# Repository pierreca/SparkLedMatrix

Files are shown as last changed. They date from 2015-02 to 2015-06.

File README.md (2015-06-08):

The end goal of this project is to build a Matrix of 16 8x8 LED Matrices (NFM-12883) driven from a spark core that can be used to display... stuff :grin:

## Current status:
- [x] Code to make text scroll across multiple matrices seems to work with 2 matrices.
- [x] First version of the PCB works fine (silkscreen isn't great though)
- [x] Connect the current prototype to the Spark cloud
- [x] Display messages sent to the device using the Spark cloud API
- [x] Clean PCB silk screen
- [x] Order more PCBs
- [x] Build more Matrices
- [x] Build and order a "motherboard" on which LED matrix modules will be connected.
- [x] Test the "motherboard".
- [x] Cleanup code style.
- [x] Implement "Line" abstraction layer that will allow to update and render both lines independently
- [x] Design case with OpenBeam and laser-cut acrylic
- [x] Build website to simply send messages to the LED Matrix
- [X] Build an API endpoint in the website.
- [ ] Add UI to turn on/off the LED Matrix from the Azure website. (Right the equivalent can be done by sending empty messages)
- [ ] Optimize rendering routine (see below in the "Optimization Opportunity section")

## Hardware
* [NFM-12883AS-11 LED Matrix](https://upverter.com/upn/b3a03be171307eb0/)
* [AS1100PL driver (MAX7219 drop-in replacement)](https://www.modmypi.com/as1100pl-led-driver)
* [Spark Core](http://www.spark.io)
* Custom Backpack PCB [Upverter](https://upverter.com/pierreca/2dc3fadd41948de2/NFM-12883-Backpack/) - [OshPark](https://oshpark.com/shared_projects/Awyc02gR)
* Custom Motherboard PCB [Upverter](https://upverter.com/pierreca/2f7e1367325db8bc/Spark-LED-Matrix-Motherboard-2/) - [Oshpark] (https://oshpark.com/shared_projects/4Sw3dNy7)

## Custom PCB
The backpack is my first PCB built using Upverter and OshPark. It's exactly the size of an NFM-12883 LED Matrix, and has the LED matrix on one side, and the driver and passive components on the other, allowing to line-up horizontally and/or vertically  multiple LED matrices.

The motherboard is my second PCB, also built using Upverter and OshPark. it fits 2 lines of 8 matrices each.

## Code
Currently the code is super basic and just scrolls or displays statically a message received from a Spark Cloud API across LED Matrices hooked up to a spark core. the code is written so that adding more LED Matrices is really easy and amounts to just changing one value.

### Making the message scroll
The LedControl library found on spark.io is a port from the Arduino LedControl library and contains basic functions such as piloting each LED individually, displaying letters using a monospaced font (called cp437) and "tweening" letters meaning scrolling a letter out while the next scrolls in.

Since this was a little too basic to obtain a message scrolling on multiple adjacent LED matrices I wrote additional functions that make text scroll across multiple matrices in 2 different ways: either using the default monospaced font (which will always amount to one letter per matrix) or that trims whitespace to make it more readable and waste less columns. I've also added a method to simply statically display text on multiple matrices (trimming spaces).

### Optimization opportunity
The current rendering routine is column-based, which means we calculate and render columns one by one. this is based of the LedControl library implementation but it's very inefficient since each column takes 8 SPI messages to transfer (one for each LED). Switching to a line-based rendering algorithm would require only one SPI message per line, which means we'd render a full LED matrix in 8 messages instead of 64.

### Case design
I wanted to do something simple with OpenBeam aluminium extrusions, but the form-factor doesn't allow for use of their regular L-brackets. Instead, I'm laser-cutting acrylic plates (black on the sides, dark transparent grey in front). The current version doesn't account for material lost during laser-cutting (meaning the edges are not perfectly aligned, there's a 0.5 millimeters error) and does not include mounting holes on the inside plate and power-supply cable hole at the back (I manually drilled those).

### Website
The SparkLedServer folder contains a super simple node.js/express based app that can be deployed to any cloud infrastructure (mine went on Azure). It will require the Spark access token and device ID in environment variables to function (otherwise you'll get an Authentication error).
Since it's super easy and quick to change these in Azure, I'd rather have the service configured this way than using the Spark/Particle authentication widget since I don't want to have to enter my username/password every time. Even though it means that anyone can access the service and send messages to the device. I'll change that if it becomes a problem. 

### API
The API is extremely simple and also described in index.js. It's just a REST endpoint at the /api path that needs to be sent a POST request with the following parameters:
* line: 0 or 1 for first or second line
* scrollDelay: a postive integer of the delay between each iteration of the scrolling mechanism, in milliseconds. 0 means no scrolling.
* message: the message to be sent, must be less than 63 characters (Particle API limitation).

## Pictures
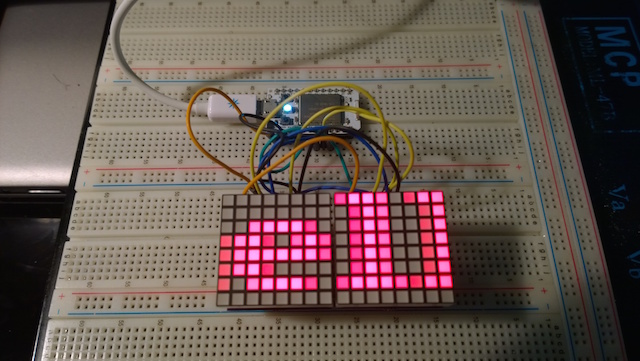
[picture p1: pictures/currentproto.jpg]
Current prototype

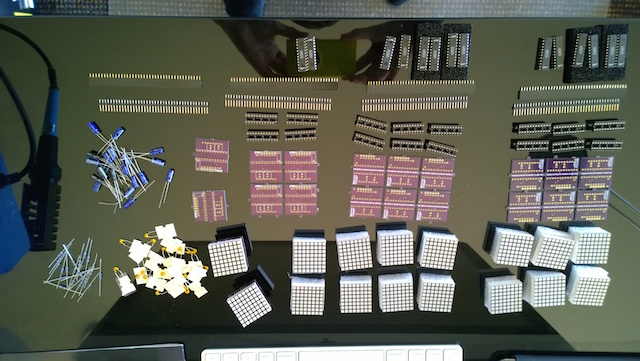
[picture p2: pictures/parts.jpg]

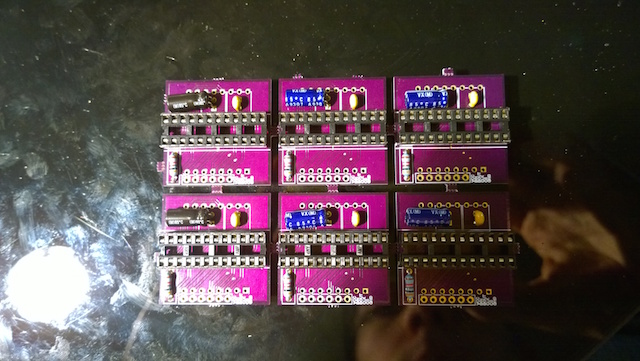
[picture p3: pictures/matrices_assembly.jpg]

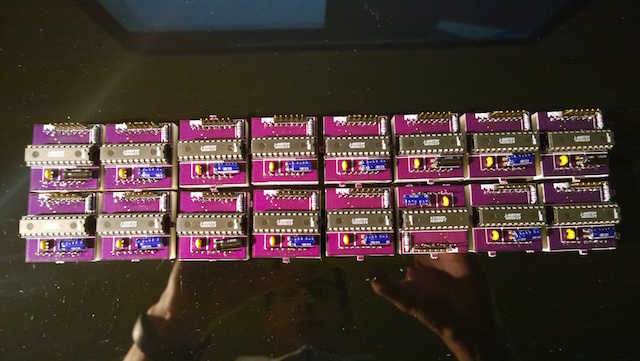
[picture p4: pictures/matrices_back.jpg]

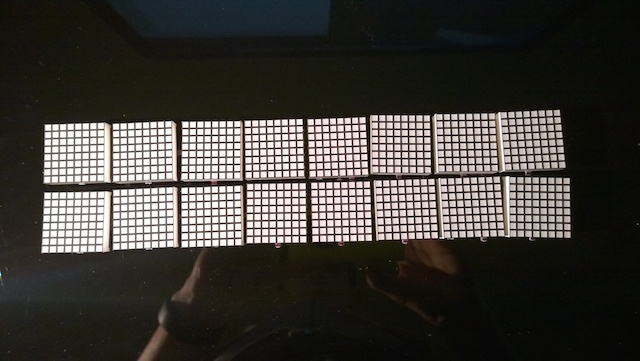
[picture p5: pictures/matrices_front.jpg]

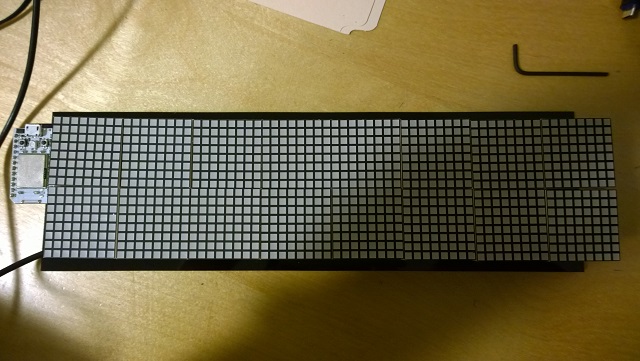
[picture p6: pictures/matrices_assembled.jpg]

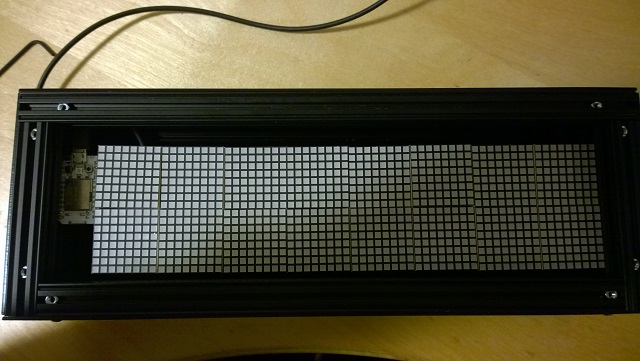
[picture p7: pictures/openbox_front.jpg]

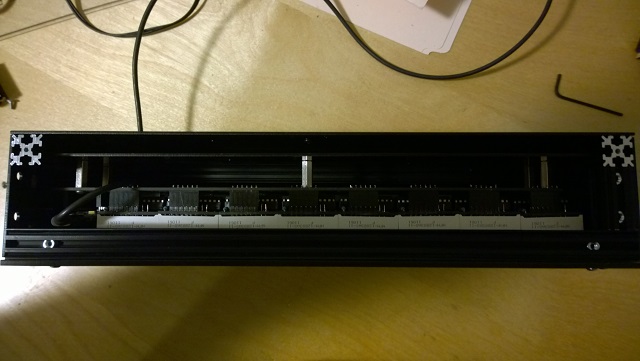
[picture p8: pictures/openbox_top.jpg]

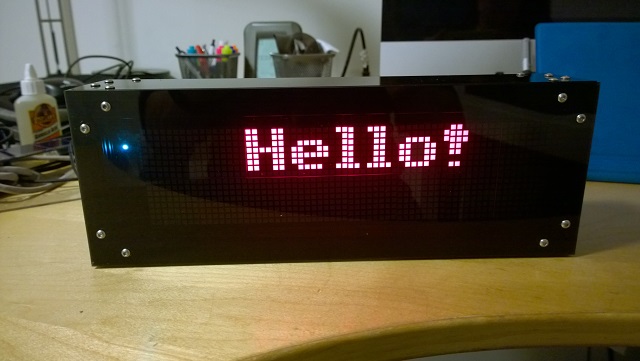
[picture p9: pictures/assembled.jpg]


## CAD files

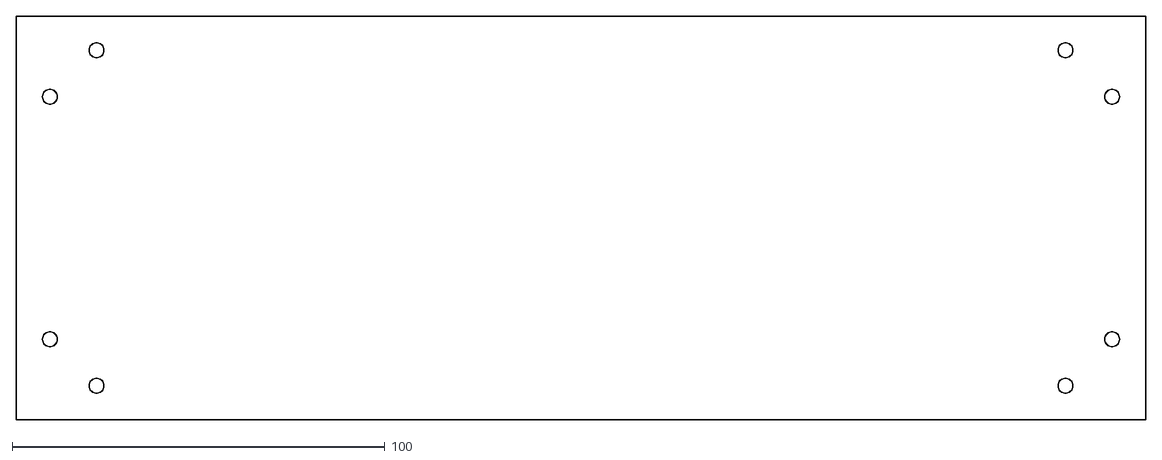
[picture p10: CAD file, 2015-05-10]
case/exports/front_plate.dxf
303.2 x 108.2

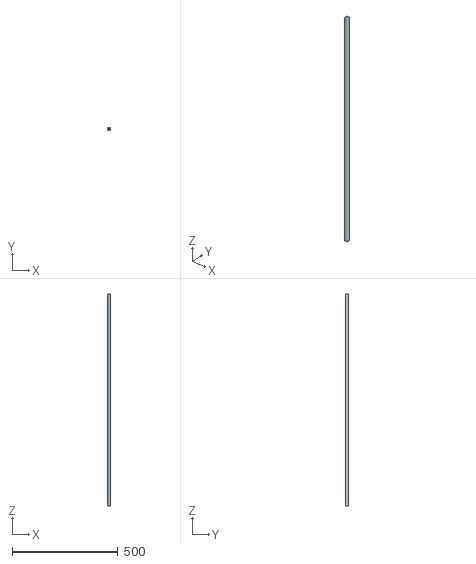
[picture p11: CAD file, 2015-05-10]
case/ob_1515.stl
15.0 x 15.0 x 1000.0

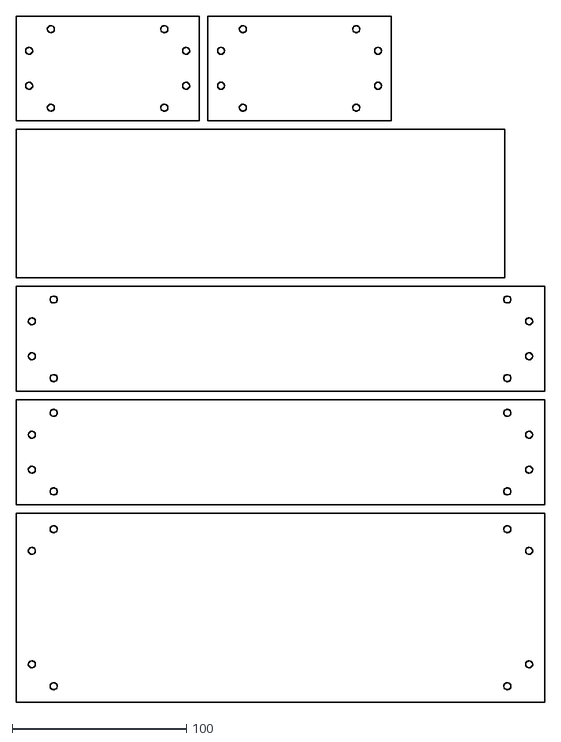
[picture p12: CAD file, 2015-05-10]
case/exports/case_flat.dxf
303.2 x 393.2

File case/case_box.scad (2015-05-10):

use <case_elements.scad>;
include <case_dimensions.scad>;

// file ob_1515.stl was found from:
// http://www.thingiverse.com/thing:30521/#files

module ob_1515(length)
{
    intersection()
    {
        cube([20,20,length]);
        import("ob_1515.stl");
    }
}

module ob_chassis(offset_x, offset_y, offset_z)
{
translate([offset_x, offset_y, offset_z])
{
    // Front, Horizontal
    translate([0,0,ob_width])
        rotate([0, 90, 0])
            ob_1515(300);

    translate([ob_width, 0, 90 + ob_width])
        rotate([0, 90, 0])
            ob_1515(270);

    // Back, Horizontal
    translate([0, lr_height - ob_width, ob_width])
        rotate([0, 90, 0])
            ob_1515(300);

    translate([ob_width, lr_height - ob_width, 90 + ob_width])
        rotate([0, 90, 0])
            ob_1515(270);

    // Left, Vertical
    translate([0,0, ob_width])
        ob_1515(90);
        
    translate([0, 30 + ob_width, ob_width])
        ob_1515(90);

    // Right, Vertical
    translate([300 - ob_width,0, ob_width])
        ob_1515(90);
        
    translate([300 - ob_width, 30 + ob_width, ob_width])
        ob_1515(90);

         
    // Left, Horizontal
    translate([0, ob_width, ob_width])
        rotate([-90, 0, 0])
            ob_1515(30);

           
    translate([0, ob_width, 90 + ob_width])
        rotate([-90, 0, 0])
            ob_1515(30);

    // Right, Horizontal
    translate([300 - ob_width, ob_width, ob_width])
        rotate([-90, 0, 0])
            ob_1515(30);
            
    translate([300 - ob_width, ob_width, 90 + ob_width])
        rotate([-90, 0, 0])
            ob_1515(30);
}
}

module side_plates()
{
    // Back plate
    translate([0, 60 + 2 * black_thickness, 0])
        rotate([90,0,0]) 
            fb_plate(0,0);

    // Front plate
    translate([0, black_thickness, 0])
        rotate([90,0,0]) 
            fb_plate(0,0);

    // Top plate
    translate([0, black_thickness, fb_height - black_thickness])
        tb_plate(0,0);

    // Bottom plate
    translate([0, black_thickness, 0])
        tb_plate(0,0);

    // Left plate
    translate([black_thickness, black_thickness, black_thickness])
        rotate([0, -90, 0])
            lr_plate(0, 0);

    // Right plate
    translate([fb_width, black_thickness, black_thickness])
        rotate([0, -90, 0])
            lr_plate(0, 0);

    // Mounting plate
    translate([10, 60 - 7.5 + black_thickness, 10])
        rotate([90,0,0]) 
            int_plate(0,0);
}

ob_chassis(black_thickness, black_thickness, black_thickness);

side_plates();

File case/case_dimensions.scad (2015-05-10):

black_thickness = 1.5875;
smoke_thickness = 3.175;

ob_width = 15;
slot_depth = 5;

/****** dimensions ******/
// front/back
fb_width = 300 + 2 * black_thickness;
fb_height = 90 + ob_width + 2 * black_thickness;

// left/right
lr_width = 90 + ob_width;
lr_height = 30 + 2 * ob_width;

// top/bottom
tb_width = fb_width;
tb_height = lr_height;

// mounting plate
int_width = 270 + 2 * slot_depth;
int_height = 90 - ob_width + 2 * slot_depth;

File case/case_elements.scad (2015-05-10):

include <case_dimensions.scad>

module black_plate(width, height)
{
    color("black")
        cube([width, height, black_thickness]);   
}

module smoke_plate(width, height)
{
    color("gray")
        cube([width, height, black_thickness]);   
}

module hole(offset_x, offset_y)
{
    translate([offset_x, offset_y, 0])
        cylinder(h=10, r=2, center=true);
}

module fb_plate(offset_x, offset_y) 
{
    a = 20 + black_thickness;
    b = 7.5 + black_thickness;
    
    translate([offset_x, offset_y, 0])
        difference()
        {
            black_plate(fb_width, fb_height);
            hole(a, b);
            hole(b, a);
            hole(b, fb_height - a);
            hole(a, fb_height - b);
            hole(fb_width - a, b);
            hole(fb_width - b, a);
            hole(fb_width - a, fb_height - b);
            hole(fb_width - b, fb_height - a);
        }
}

module lr_plate(offset_x, offset_y) 
{
    a = 20;
    b = 7.5;
    
    translate([offset_x, offset_y, 0])
        difference()
        {
            black_plate(lr_width, lr_height);
            hole(a, b);
            hole(b, a);
            hole(b, lr_height - a);
            hole(a, lr_height - b);
            hole(lr_width - a, b);
            hole(lr_width - b, a);
            hole(lr_width - a, lr_height - b);
            hole(lr_width - b, lr_height - a);
        }
}

module tb_plate(offset_x, offset_y) 
{
    a = 20 + black_thickness;
    b = 7.5 + black_thickness;
    c = 20;
    d = 7.5;
    
    translate([offset_x, offset_y, 0])
        difference()
        {
            black_plate(tb_width, tb_height);
            hole(a, d);
            hole(b, c);
            hole(b, tb_height - c);
            hole(a, tb_height - d);
            hole(tb_width - a, d);
            hole(tb_width - b, c);
            hole(tb_width - a, tb_height - d);
            hole(tb_width - b, tb_height - c);
        }
}

module int_plate(offset_x, offset_y)
{
    translate([offset_x, offset_y, 0])
        black_plate(int_width, int_height);
}

module front_plate()
{
    fb_plate(0,0);
}

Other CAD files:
case/case_flat.scad
case/front_plate.scad

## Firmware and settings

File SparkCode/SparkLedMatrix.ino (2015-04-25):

#include "DisplayLine.h"

#define MATRIX_PER_LINE 8
#define LINE_COUNT 2
#define SPARK_API_MSG_SIZE 63

DisplayLine* lines[LINE_COUNT];

uint8_t cs_0 = A5;
uint8_t clk_0 = A6;
uint8_t din_0 = A7;

uint8_t cs_1 = D0;
uint8_t clk_1 = D1;
uint8_t din_1 = D2;

char recvBuffer[SPARK_API_MSG_SIZE];
int recvBufferLength = 0;

bool newMessage = false;
int activeLine = 0;

void setup() {
    lines[0] = new DisplayLine(din_0, clk_0, cs_0, MATRIX_PER_LINE); // DIN, CLK, CS, HowManyDisplays
    lines[1] = new DisplayLine(din_1, clk_1, cs_1, MATRIX_PER_LINE); // DIN, CLK, CS, HowManyDisplays

    lines[0]->activate(8);
    lines[0]->setScrollDelay(50);
    lines[0]->setText("Hello!", 7);

    lines[1]->activate(8);

    Spark.variable("recvBuffer", recvBuffer, STRING);
    Spark.variable("activeLine", &activeLine, INT);
    Spark.variable("recvBufferLength", &recvBufferLength, INT);
    Spark.function("setMessage", setMessage);
    Spark.function("setActiveLine", setActiveLine);
    Spark.function("setScrollDelay", setScrollDelay);
}

void loop() {
    if (newMessage) {
        lines[activeLine]->setText(recvBuffer, recvBufferLength);
        newMessage = false;
    }

    for (int i = 0; i < LINE_COUNT; i++) {
        lines[i]->refreshDisplay();
    }
}

int setMessage(String msg) {
    recvBufferLength = msg.length() + 1;
    msg.toCharArray(recvBuffer, recvBufferLength);
    newMessage = true;
    return recvBufferLength - 1;
}

int setActiveLine(String msg) {
    int new_activeLine = msg.toInt();

    if (new_activeLine < 0 || new_activeLine >= LINE_COUNT) {
        return -1;
    } else {
        activeLine = new_activeLine;
    }

    return activeLine;
}

int setScrollDelay(String msg) {
    int new_scrollDelay = msg.toInt();
    if (new_scrollDelay < 0) {
        return -1;
    } else {
        lines[activeLine]->setScrollDelay(new_scrollDelay);
    }

    return new_scrollDelay;
}

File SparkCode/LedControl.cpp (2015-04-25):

#include "LedControl.h"

/*************************************************************************************/

//the opcodes for the MAX7221 and MAX7219
#define OP_NOOP   0
#define OP_DIGIT0 1
#define OP_DIGIT1 2
#define OP_DIGIT2 3
#define OP_DIGIT3 4
#define OP_DIGIT4 5
#define OP_DIGIT5 6
#define OP_DIGIT6 7
#define OP_DIGIT7 8
#define OP_DECODEMODE  9
#define OP_INTENSITY   10
#define OP_SCANLIMIT   11
#define OP_SHUTDOWN    12
#define OP_DISPLAYTEST 15

LedControl::LedControl(int dataPin, int clkPin, int csPin, int numDevices) {
    SPI_MOSI=dataPin;
    SPI_CLK=clkPin;
    SPI_CS=csPin;

    if(numDevices<=0 || numDevices>8 ) {
        numDevices=8;
    }

    maxDevices = numDevices;
    maxCols = maxDevices * colsPerDisplay;
    pinMode(SPI_MOSI,OUTPUT);
    pinMode(SPI_CLK,OUTPUT);
    pinMode(SPI_CS,OUTPUT);
    digitalWrite(SPI_CS,LOW);
    SPI_MOSI=dataPin;

    for(int i=0;i<64;i++) {
        status[i]=0x00;
    }

    for(int i=0;i<maxDevices;i++) {
        spiTransfer(i,OP_DISPLAYTEST,0);
        //scanlimit is set to max on startup
        setScanLimit(i,7);
        //decode is done in source
        spiTransfer(i,OP_DECODEMODE,0);
        setIntensity(i,1);
        clearDisplay(i);
        //we go into shutdown-mode on startup
        shutdown(i,true);
    }
}

int LedControl::getDeviceCount() {
    return maxDevices;
}

void LedControl::shutdown(int addr, bool b) {
    if(addr<0 || addr>=maxDevices) {
        return;
    }

    if(b) {
        spiTransfer(addr, OP_SHUTDOWN,0);
    } else {
        spiTransfer(addr, OP_SHUTDOWN,1);
    }
}

void LedControl::setScanLimit(int addr, int limit) {
    if(addr<0 || addr>=maxDevices) {
        return;
    }

    if(limit>=0 && limit<8) {
        spiTransfer(addr, OP_SCANLIMIT,limit);
    }
}

void LedControl::setIntensity(int addr, int intensity) {
    if(addr<0 || addr>=maxDevices) {
        return;
    }

    if(intensity>=0 && intensity<16) {
        spiTransfer(addr, OP_INTENSITY,intensity);
    }
}

void LedControl::clearDisplay(int addr) {
    int offset;

    if(addr<0 || addr>=maxDevices) {
        return;
    }

    offset=addr*8;

    for(int i=0;i<8;i++) {
        status[offset+i]=0;
        spiTransfer(addr, i+1,status[offset+i]);
    }
}

void LedControl::setLed(int addr, int row, int column, bool state) {
    int offset;
    byte val=0x00;

    if(addr<0 || addr>=maxDevices) {
        return;
    }

    if(row<0 || row>7 || column<0 || column>7) {
        return;
    }

    offset=addr*8;
    val=128 >> column;

    if(state) {
        status[offset+row]=status[offset+row]|val;
    } else {
        val=~val;
        status[offset+row]=status[offset+row]&val;
    }

    spiTransfer(addr, row+1,status[offset+row]);
}

void LedControl::setRow(int addr, int row, byte value) {
    int offset;
    if(addr<0 || addr>=maxDevices) {
        return;
    }

    if(row<0 || row>7) {
        return;
    }

    offset=addr*8;
    status[offset+row]=value;
    spiTransfer(addr, row+1,status[offset+row]);
}

void LedControl::setColumn(int addr, int col, byte value) {
    byte val;

    if(addr<0 || addr>=maxDevices) {
        return;
    }

    if(col<0 || col>7) {
        return;
    }

    for(int row=0;row<8;row++) {
        val=value >> (7-row);
        val=val & 0x01;
        setLed(addr,row,col,val);
    }
}

void LedControl::setDigit(int addr, int digit, byte value, bool dp) {
    int offset;
    byte v;

    if(addr<0 || addr>=maxDevices) {
        return;
    }

    if(digit<0 || digit>7 || value>15) {
        return;
    }

    offset=addr*8;
    v=charTable[value];

    if(dp) {
        v|=128;
    }

    status[offset+digit]=v;
    spiTransfer(addr, digit+1,v);

}

void LedControl::setChar(int addr, int digit, char value, bool dp) {
    int offset;
    byte index,v;

    if(addr<0 || addr>=maxDevices) {
        return;
    }

    if(digit<0 || digit>7) {
        return;
    }

    offset=addr*8;
    index=(byte)value;

    if(index >127) {
        //nothing define we use the space char
        value=32;
    }

    v=charTable[index];

    if(dp) {
        v|=128;
    }

    status[offset+digit]=v;
    spiTransfer(addr, digit+1,v);
}

void LedControl::spiTransfer(int addr, volatile byte opcode, volatile byte data) {
    //Create an array with the data to shift out
    int offset=addr*2;
    int maxbytes=maxDevices*2;

    for(int i=0;i<maxbytes;i++) {
        spidata[i]=(byte)0;
    }

    //put our device data into the array
    spidata[offset+1]=opcode;
    spidata[offset]=data;

    //enable the line
    digitalWrite(SPI_CS,LOW);

    //Now shift out the data
    for(int i=maxbytes;i>0;i--) {
        shiftOut(SPI_MOSI,SPI_CLK,MSBFIRST,spidata[i-1]);
    }

    //latch the data onto the display
    digitalWrite(SPI_CS,HIGH);
}

void LedControl::setLetter (int addr, const byte c){
    for (byte col = 0; col < 8; col++) {
        setColumn(addr, 7-col, cp437_font [c] [col]);
    }
}  // end of letter

void LedControl::tweenLetters (int addr, const byte c1, const byte c2, int speed){
    for (byte step = 0; step < 8; step++){
        for (byte col = 0; col < 8; col++){
            if(col<8-step) {
                setColumn(addr, 7-col, cp437_font [c1] [col+step]);
            } else {
                setColumn(addr, 7-col, cp437_font [c2] [col+step-8]);
            }
        }

        delay(speed);
    }
}

/* @pierreca's additions ************************************************************************/
void LedControl::setText(char *message, int messageLength) {
    int limit = messageLength < maxDevices ? messageLength : maxDevices;

    for(int i = 0; i < limit; i++) {
        setLetter(i, message[i]);
    }
}

void LedControl::scrollText(char *message, int messageLength, int speed) {
    for (int i = 0; i < maxDevices; i++) {
        clearDisplay(i);
    }

    for (int j = 0; j < (messageLength - 1) * 8; j++) {
        for(int i = maxCols; i >= 0; i--) {
            setColumn(i / 8, i % 8, cp437_font[message[(maxCols - i + j) / 8]][(maxCols - i + j) % 8]);
        }
        delay(speed);
    }
}
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

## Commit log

2015-02-23 fixed scroll feature and added static text display
    [LedControl.cpp, SparkLedMatrix.ino]
2015-04-20 Get the code to actually display something. what's next: - clean code style (currently it's a mix of multiple coding styles that is ugly) - implement a better line logic in order to update one line w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
2015-05-10 First version of the case with OpenBeam
    [case_box.scad, case_dimensions.scad, case_elements.scad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]
2015-05-10 Small corrections to the case files
    [case_box.scad, case_flat.scad]
2015-05-10 Front plate and DXF exports
    [case_flat.dxf, front_plate.dxf, front_plate.scad]
2015-06-01 Set DeviceId/AccessToken as env variables instead of query string parameters
